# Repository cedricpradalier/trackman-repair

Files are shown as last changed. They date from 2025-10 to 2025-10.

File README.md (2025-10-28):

## Presentation
This repository contains my references for repairing the discontinued Logitech Trackball (I only experienced with the 4-button version).

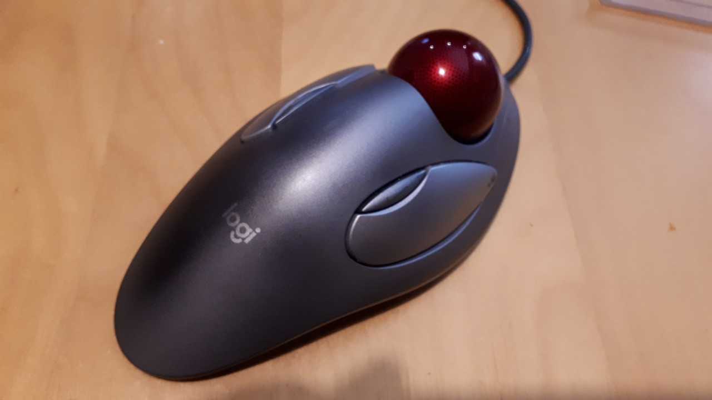
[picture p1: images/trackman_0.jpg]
Logitech Trackman


The main failure point for these trackball is the buttons, becoming unreliable, either not clicking or always double/triple clicking. 

## Inspiration
I got inspired from two contributions:
 * This youtube video detailing how to change the mouse microswitches: [https://www.youtube.com/watch?v=oGf5q5bjra0]
 * These designs and instructions to reinforce the mouse internal structure: [https://www.thingiverse.com/thing:3416522] (Note, there are also upgraded instructions for the 2-button version here: [https://www.thingiverse.com/thing:4754168]). I followed the instruction there to prepare the mouse and I printed the two simple parts that are inserted around the center screw to increase the rigidity.

The proposed design is required at a much later stage than what I did for my mouse: they require removing the internal support structure of the button PCB and replacing it completely with a 
printed model.

In my case, the internal structure holding the PCB was still sound but it became a bit soft, making the PCB wiggle and reducing the reliability of the button. The design here keeps the internal structure
and fits snuggly around it, supporting and rigidifying the PCB. 
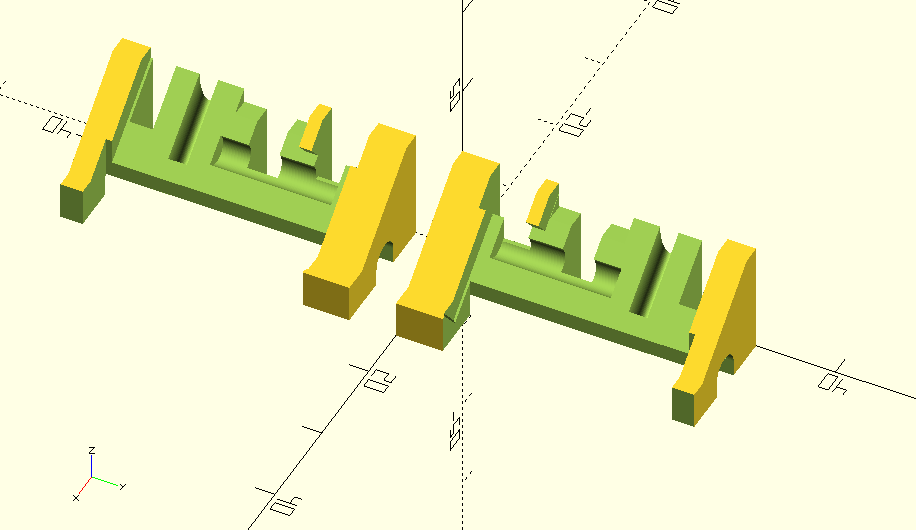
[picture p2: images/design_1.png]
Design 1


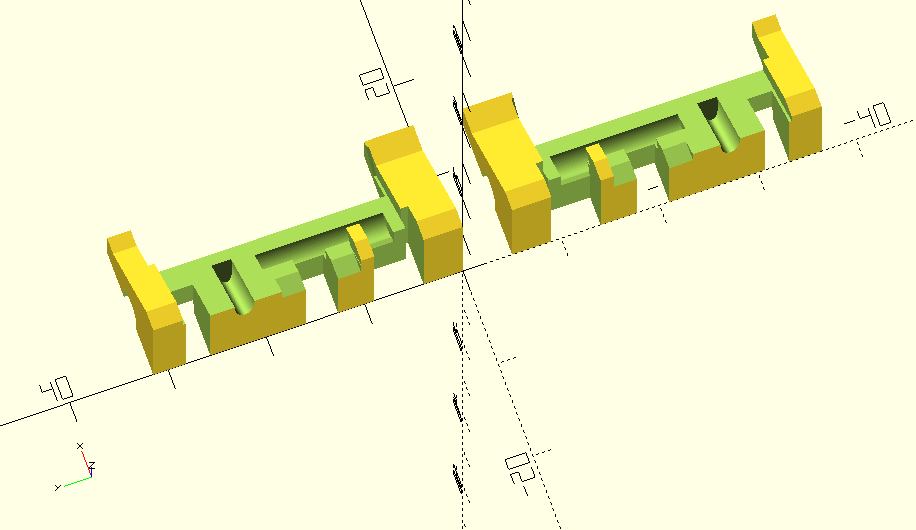
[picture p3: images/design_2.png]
Design 2


After implementing on my two mice, I identified that one switch was reliably double-clicking. I replaced it following the instructions in the video and the mouse is good to go. 

## Installation steps
Once the mouse is open, the button pcb detached from the plastic holders, and two parts printed, here are the steps:
1) clip the model around the cable on the side where you want to route it:
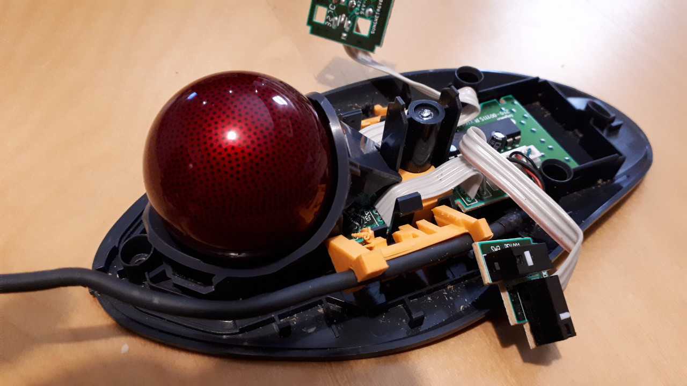
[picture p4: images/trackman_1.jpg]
Repair Step 1


2) insert the part and the cable below the PCB (the larger "foot" towards the ball):
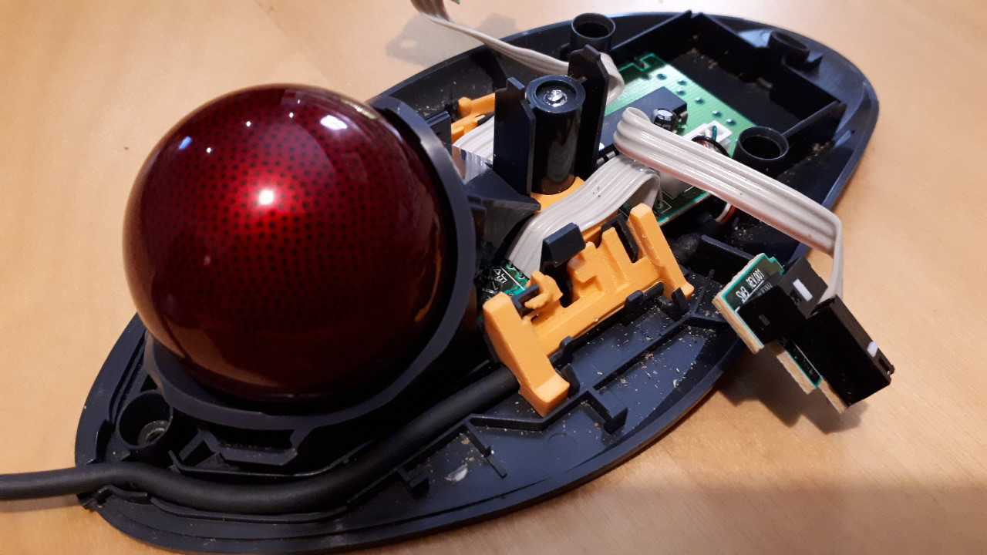
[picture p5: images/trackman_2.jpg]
Repair Step 2


3) insert the second part on the other side.
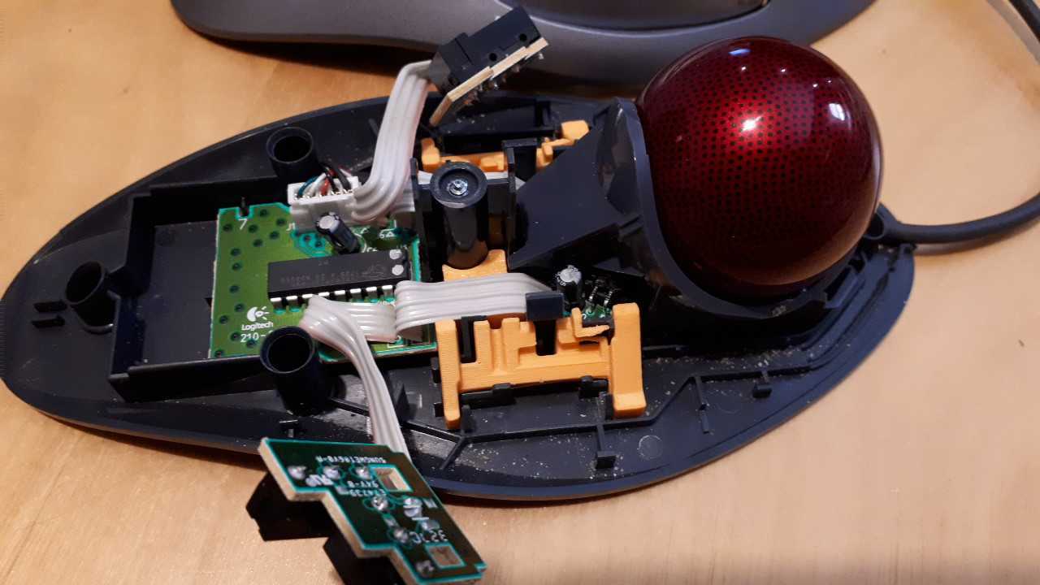
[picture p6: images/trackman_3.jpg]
Repair Step 3


4) reclip the PCBs: they need to be inserted vertically and then tilted into place. This should result in a rigid structure without forcing. In my case, I had to snip the pins of the switches below the pcb. 
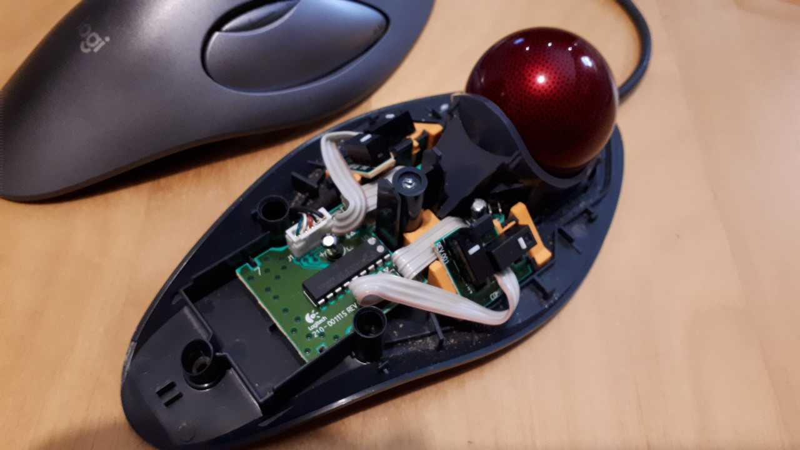
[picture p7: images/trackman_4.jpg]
Repair Step 4


5) possibly insert the rigidifying blocks at the center (seen in the picture here, design at [https://www.thingiverse.com/thing:3416522]), reroute the cable, reassemble plastic casing, and you can test the buttons. If some of them are still double clicking, you're probably good for changing the corresponding switch.  

## Troubleshooting
In one of my mice, I found that one of the button was a bit hard to click after reassembling the mouse. I unscrewed the center screw (the one below the sticker) by one turn, and it became comfortable again. Given that there are 5 screws holding the mouse case, this is a sufficient fix.

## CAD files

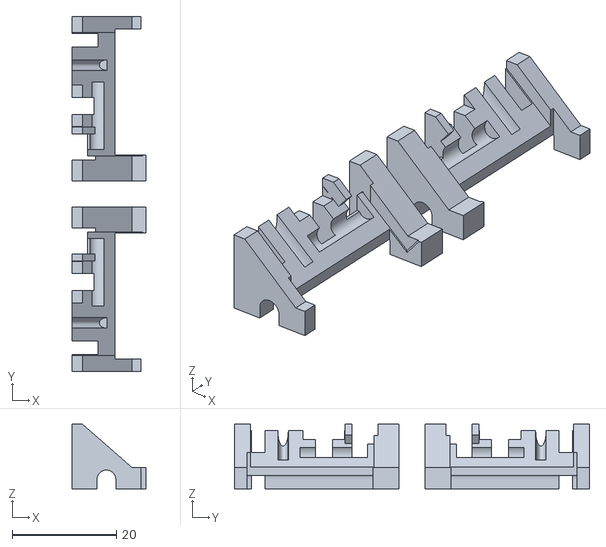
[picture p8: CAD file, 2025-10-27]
files/TrackmanSupport.stl
14.2 x 68.0 x 12.4

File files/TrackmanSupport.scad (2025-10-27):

module trackman_support () {
    difference() {

        translate([0,31.5,0]) rotate([90,0,0]) linear_extrude(31.5) {
            polygon([[0,0],[14.2,0],[14.2,4.1],[11.5,4.1],[2,12.4],[0,12.4]]);
        }

        union () {
            color("darkgreen") translate([14.5-1.6*cos(40),5,0]) rotate([40,0,90]) 
            union() {
                difference() {
                    linear_extrude(1.6+5) {
                            offset(r=0.25) polygon([[(23.2-20.5)/2,-2],
                                [23.2-(23.2-20.5)/2,-2],
                                [23.2-(23.2-20.5)/2,2.5],
                                [23.2,2.5],
                                [23.2,22.1],
                                [23.2-8.9,22.1],
                                [23.2-8.9,17.4+2], // +2 to remove overhang
                                [23.2-17.6,17.4+2],
                                [23.2-17.6,13.2],
                                [0,13.2],
                                [0,2.5],
                                [(23.2-20.5)/2,2.5]   
                            ]);
                        }
                     //translate([2,6.0,-0.01]) cube([2,1.5,2]);
                     //translate([15,6.0,-0.01]) cube([3,1.5,2]);
                }
                translate([23.2-6,22.1-14+0.5,0]) scale([1,1,2.25]) rotate([-90,0,0]) cylinder(h=14,r=1,$fn=100);
                translate([1,17.4-6.6,0]) scale([1,1.5,1.85]) rotate([0,90,0]) cylinder(h=13,r=1,$fn=100);
                //translate([5.5,6,0]) rotate([0,90,0]) cylinder(h=9,r=1,$fn=100);
            }
            translate([-0.01,25.7,-0.01]) cube([5.0,2.5,15]);
            translate([-0.01,12.7,-0.01]) cube([4.25,3.3,15]);
            translate([-0.01,10.4,17.6*sin(45)-3]) cube([4.0,8,5]);
            translate([-0.01,4,-0.01]) cube([3.0,5.0,15]);
            translate([-0.01,4,-0.01]) cube([4.5,0.75,15]);
            translate([-0.01,6,6.0]) cube([4.5,3.0,15]);
            translate([-0.01,4,8.6]) cube([4.5,3.0,15]);
            //translate([4.8,-0.01,-0.01]) cube([3.6,32.0,3.6]);
            translate([4.8,-0.01,-0.01]) cube([3.6,32.0,1.8]);
            translate([4.8+1.8,-0.01,1.8]) rotate([-90,0,0]) cylinder(h=32.0,r=1.8,$fn=100);
            translate([8.25,5.,-0.01]) cube([8.0,24.1,10]);
            translate([11,5.,-0.01]) cube([8.0,24.1,10]);
            //translate([8.0,5,-0.01]) cube([8.0,4.5,8.0]);
            //translate([8.0,20.5,-0.01]) cube([8.0,9.1,8.0]);
            translate([13.2,29,-0.01]) cube([8.0,24.6,4.2]);
        }
    }
}

trackman_support();
translate([0,-5,0]) mirror([0,1,0]) trackman_support();
